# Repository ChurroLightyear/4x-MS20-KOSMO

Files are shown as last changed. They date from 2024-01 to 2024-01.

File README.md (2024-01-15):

# 4x MS20 KOSMO (ROUGH DRAFT)
This is a stackable but very crude MS20 filter based on the KS20 by Kassutronics

This has been tested and is working with some 100% neccesary changes

***The transitor footprints ended up backwords on Kicad.

Theres a few changes that are planned with this filter but it's up and working great atm. Everything is offboard wired from the PCBs. I drilled a custom alumunum panel and made some changes to the circuit.

The biggest change was the glaring backwords transistor footprints. This clearly will not work at all without those placed correctly. Then the cutoff, shape (lp/hp), the cv amount pots have the pad positions reversed (square pad is leg 3 not 1)
I updated the schematic and the Old gerbers to have the transitors placed correctly but double check.
I took out out r23 and added a 2k trimpot in place This adjusts the range of the throw
I changed r19 to a 47k. I was finding the CV range to be kind of dissapointing with  the original 100k.
It's not on the PCB but I added the trimpots for adjusting the scale and weight of the filter and connected the weight like a second cv knob with a trimpot and the scale adjusts the range
I also added a 6db/12db slope option like eddybergmans design https://www.eddybergman.com/2019/12/synthesizer-build-part-12-korg-ms20.html
The trimpots are in the schematic but for the 6db/12db option follow the schematic I'll update it in the future
The Ms20 new is for a future plan with using 90 degree headers and adding a jack panel and a pot panel with angled holes for the trimpots.
!!!theres no protection diodes on this circuit
for a single filter you may be able to get away without adding the trimpots but the variability in the filters are far too great.
I used bc558s instead of 557s like kassutronics also and I've heard you should match them but I didn't and it came out fine

The files I used are in the OLD folders and the new folders a future (probably a good bit from now) plan

The new PCBs will have a Panel, control PCB, jacks pcb, and 4 filter stacks on each. The resistor values will be where I found to like them. There will be 2 90 degree mounted adjustment trimpots. Switches for the 12db, 6db shelfs. 4 sets of 90 degree header pins to attach the pcbs to the main board. 1 filter knob, 2 dpdt (on/on) switches for the shelf (filters 1/2 and 3/4), 2 stereo pots (resonance 1/2 and 3/4) 4 cv level pots, 4 lp/hp mix pot, 4 drive pots, 4 input jacks, 4 output jacks and 4 cv jacks. All with no off board wiring (currently its around 100 wires) and removing the standoff holes and power header slots.

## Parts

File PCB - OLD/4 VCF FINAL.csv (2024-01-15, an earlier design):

Ref | Qnty | Value | Cmp name | Footprint | Description | Vendor
+1, +2, | 2 | LED | LED | ao_tht:PinHeader_1x02_P2.54mm_Vertical | Light emitting diode
C1, C2, | 2 | 1n | C | KOSMO:BOX cap | Unpolarized capacitor
C3, | 1 | 470n | C | KOSMO:BOX cap | Unpolarized capacitor
C4, | 1 | 4.7n | C | KOSMO:BOX cap | Unpolarized capacitor
C5, C6, C7, C8, C11, C12, | 6 | 100n | C | KOSMO:BOX cap | Unpolarized capacitor
C9, C10, | 2 | 10u | CP | KOSMO:Elec CAP | Polarized capacitor | Tayda
Q1, Q2, | 2 | BC558 | BC558 | KOSMO:Transistor | 0.1A Ic, 30V Vce, PNP Small Signal Transistor, TO-92
R1, R2, R3, R4, R19, R20, | 6 | 100K | R | KOSMO:R | Resistor | Tayda
R5, R17, | 2 | 4.7k | R | KOSMO:R | Resistor | Tayda
R6, R7, R11, R12, | 4 | 220 | R | KOSMO:R | Resistor | Tayda
R8, R14, R18, | 3 | 10k | R | KOSMO:R | Resistor | Tayda
R9, R10, R13, | 3 | 10K | R | KOSMO:R | Resistor | Tayda
R15, | 1 | 1k | R | KOSMO:R | Resistor | Tayda
R16, | 1 | 47k | R | KOSMO:R | Resistor | Tayda
R21, | 1 | 4.7K | R | KOSMO:R | Resistor | Tayda
R22, | 1 | 470k | R | KOSMO:R | Resistor | Tayda
R23, | 1 | 1.8k | R | KOSMO:R | Resistor | Tayda
CUTOFF1, | 1 | 100K | R_Potentiometer | ao_tht:PinHeader_1x03_P2.54mm_Vertical | Potentiometer
DRIVE1, | 1 | 100K | R_Potentiometer | ao_tht:PinHeader_1x03_P2.54mm_Vertical | Potentiometer
RESONANCE1, | 1 | 100K | R_Potentiometer | ao_tht:PinHeader_1x03_P2.54mm_Vertical | Potentiometer
LP/HP1, | 1 | 100K | R_Potentiometer | ao_tht:PinHeader_1x03_P2.54mm_Vertical | Potentiometer
RV4, | 1 | 100K | R_Potentiometer | ao_tht:PinHeader_1x03_P2.54mm_Vertical | Potentiometer
U1, | 1 | TL072 | TL072 | KOSMO:TL072 | Dual Low-Noise JFET-Input Operational Amplifiers, DIP-8/SOIC-8
U2, | 1 | TL074 | TL074 | KOSMO:TL074 | Quad Low-Noise JFET-Input Operational Amplifiers, DIP-14/SOIC-14
U3, | 1 | LM13700 | LM13700 | Package_DIP:DIP-16_W7.62mm | Dual Operational Transconductance Amplifiers with Linearizing Diodes and Buffers, DIP-16/SOIC-16

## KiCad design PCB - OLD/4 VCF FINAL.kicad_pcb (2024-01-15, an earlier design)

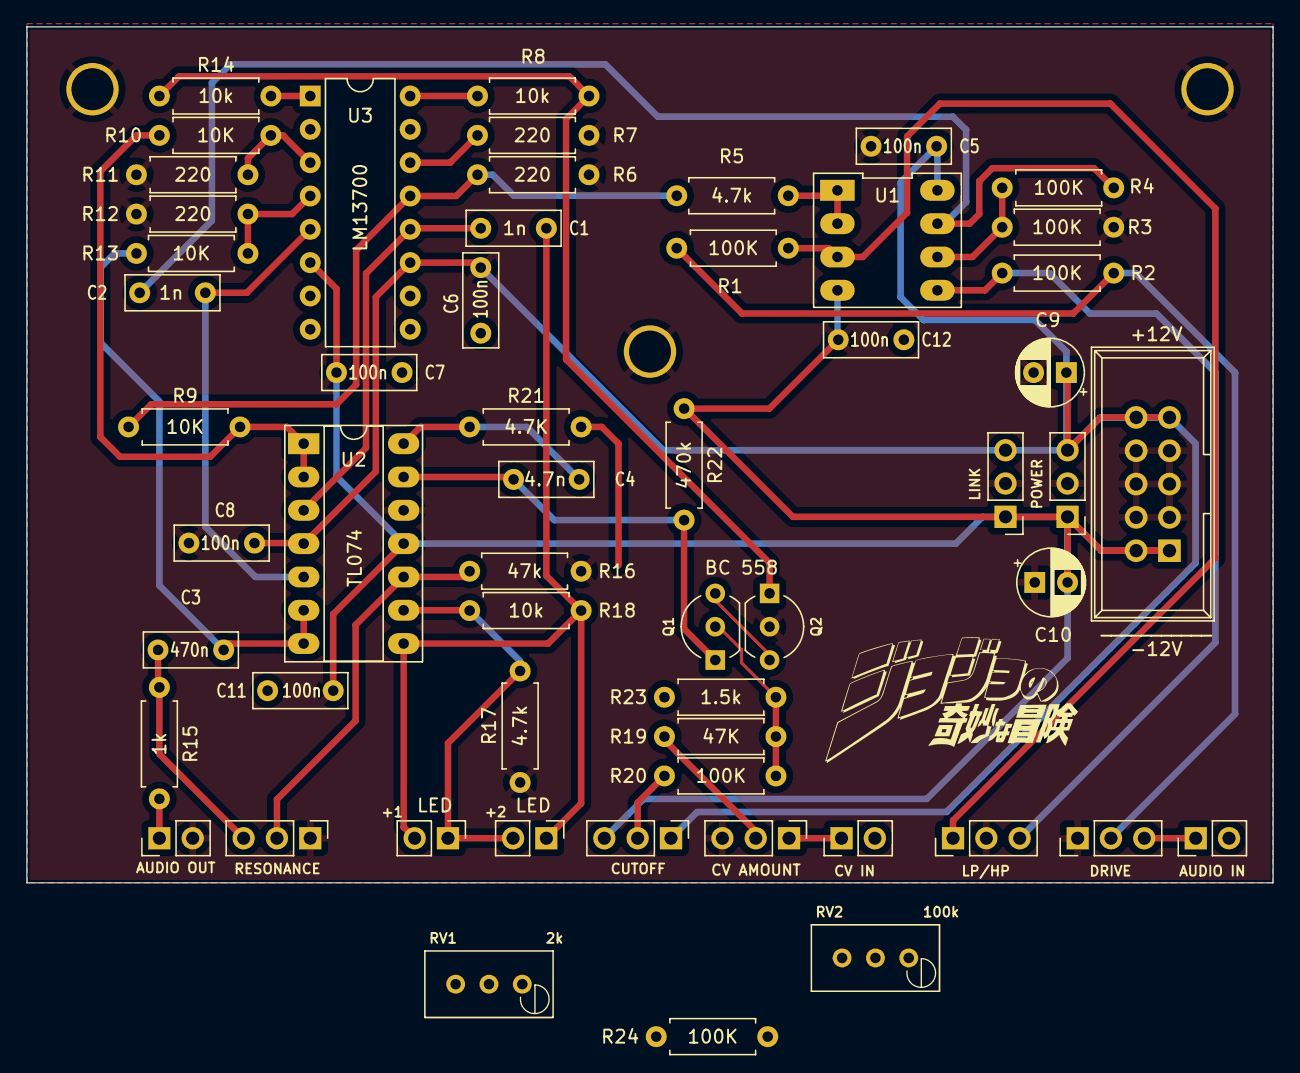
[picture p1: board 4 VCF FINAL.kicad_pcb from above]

Board: 2 copper layers, 95.0 x 65.2 mm, 56 parts (0 on the bottom side), 31 nets.

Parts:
+1, +2: LED; PinHeader_1x02_P2.54mm_Vertical
AUDIO OUT: AUDIO OUT; PinHeader_1x02_P2.54mm_Vertical
C1, C2: 1n; BOX cap
C3: 470n; BOX cap
C4: 4.7n; BOX cap
C5, C6, C7, C8, C11, C12: 100n; BOX cap
C9, C10: 10u; Elec CAP
CUTOFF: 100K; PinHeader_1x03_P2.54mm_Vertical
DRIVE: 100K; PinHeader_1x03_P2.54mm_Vertical
J0: POWER; Power_Header
J1: AUDIO IN; PinHeader_1x02_P2.54mm_Vertical
J2: CV IN; PinHeader_1x02_P2.54mm_Vertical
LINK: POWER; PinHeader_1x03_P2.54mm_Vertical
LP/HP: 100K; PinHeader_1x03_P2.54mm_Vertical
POWER: POWER; PinHeader_1x03_P2.54mm_Vertical
Q1, Q2: TO-92_Inline_Wide
R1, R2, R3, R4, R20, R24: 100K; R
R5, R17: 4.7k; R
R6, R7, R11, R12: 220; R
R8, R14, R18: 10k; R
R9, R10, R13: 10K; R
R15: 1k; R
R16: 47k; R
R19: 47K; R
R21: 4.7K; R
R22: 470k; R
R23: 1.5k; R
RESONANCE: 100K; PinHeader_1x03_P2.54mm_Vertical
RV1: 1k; Potentiometer_Bourns_3296W_Vertical
RV2: 100k; Potentiometer_Bourns_3296W_Vertical
RV4: CV AMOUNT; PinHeader_1x03_P2.54mm_Vertical
U1: TL072
U2: TL074
U3: LM13700; DIP-16_W7.62mm

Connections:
+12V: C6.1, C7.1, C8.1, C9.1, CUTOFF.1, J0.9, J0.10, LINK.3, POWER.3, RV2.1, U1.8 (V+), U2.4 (V+), U3.11 (V+)
-12V: C5.1, C10.2, C11.1, C12.1, CUTOFF.3, J0.1, J0.2, LINK.1, POWER.1, R22.1, RV2.3, U1.4 (V-), U2.11 (V-), U3.6 (V-)
CUT: Q2.1, R8.1, R14.1
GND: AUDIO OUT.2, C5.2, C6.2, C7.2, C8.2, C9.2, C10.1, C11.2, C12.2, DRIVE.1, J0.3, J0.4, J0.5, J0.6, J0.7, J0.8, LINK.2, LP/HP.2, POWER.2, Q2.2, R3.1, R6.1, R7.1, R11.1, R12.1, R16.1, R17.1, RESONANCE.1, RV1.2, RV1.3, RV4.3, U2.12 (+)
unnamed: +1.2 (A), +2.1 (K), C1.2, R18.2, U2.8
unnamed: +1.1 (K), +2.2 (A), R17.2, R18.1, U2.9 (-)
unnamed: C2.2, R4.2, U1.7
unnamed: C3.2, R15.1, RESONANCE.3
unnamed: C4.1, R21.1, U2.14
unnamed: R1.1, R2.1
unnamed: AUDIO OUT.1, R15.2
unnamed: Q1.2, R19.2, R20.2, R23.2, R24.2
unnamed: C4.2, Q1.1, R22.2, U2.13 (-)
unnamed: Q1.3, Q2.3, R21.2
unnamed: R8.2, U3.16
unnamed: R14.2, U3.1
unnamed: R23.1, RV1.1
unnamed: R24.1, RV2.2
unnamed: R1.2, U1.3 (+)
unnamed: R5.1, U1.1, U1.2 (-)
unnamed: R2.2, U1.5 (+)
unnamed: R3.2, R4.1, U1.6 (-)
unnamed: C1.1, U2.3 (+), U3.12
unnamed: R9.2, R10.1, U2.1, U2.2 (-)
unnamed: C2.1, U2.5 (+), U3.5
unnamed: C3.1, R13.2, U2.6 (-), U2.7
unnamed: R16.2, U2.10 (+)
unnamed: R7.2, U3.14 (+)
unnamed: R5.2, R6.2, R9.1, U3.13 (-)
unnamed: R10.2, R11.2, U3.3 (+)
unnamed: R12.2, R13.1, U3.4 (-)

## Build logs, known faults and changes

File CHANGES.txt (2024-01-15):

flipped backwards transistors
replaced resistors with trimpots to adjust scale and position
removed jumpers to filter level (One knob can control multiple voices)
changed cv amount resistor to 47k
place near knobs
added trimpot and 100k pot to adjust filter position
replace LP/HP pot with 4pdt switch (Low pass/hi-pass)
replace inputs with single LP/HP audio in
Make Trimmers side mounted

1 filter knob
1 LP/HP switch (possible to replace lp/hp mix knob and leave front panel room)
2 dpdt (on/on) switches for shelf control 12/6db

(Possible to condense the knob controls to have 1 for each value with VCA!?)
4 drive knobs
4 cv amount knobs
4 resonance knobs
